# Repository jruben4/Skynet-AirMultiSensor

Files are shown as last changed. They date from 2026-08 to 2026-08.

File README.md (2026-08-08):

# Skynet-AirMultiSensor

| Front | Back |
|:---:|:---:|
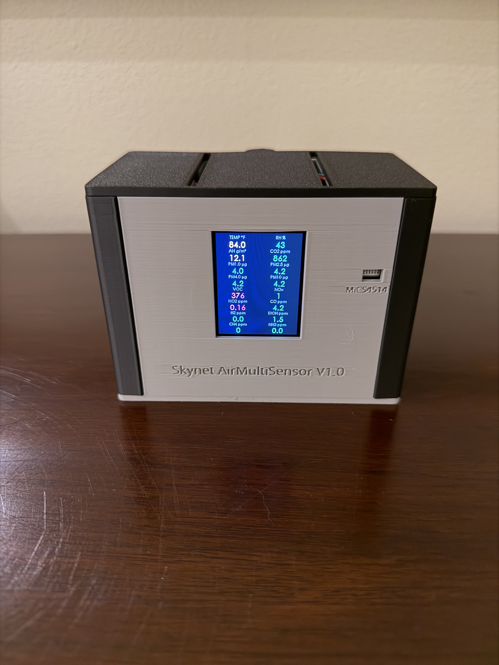
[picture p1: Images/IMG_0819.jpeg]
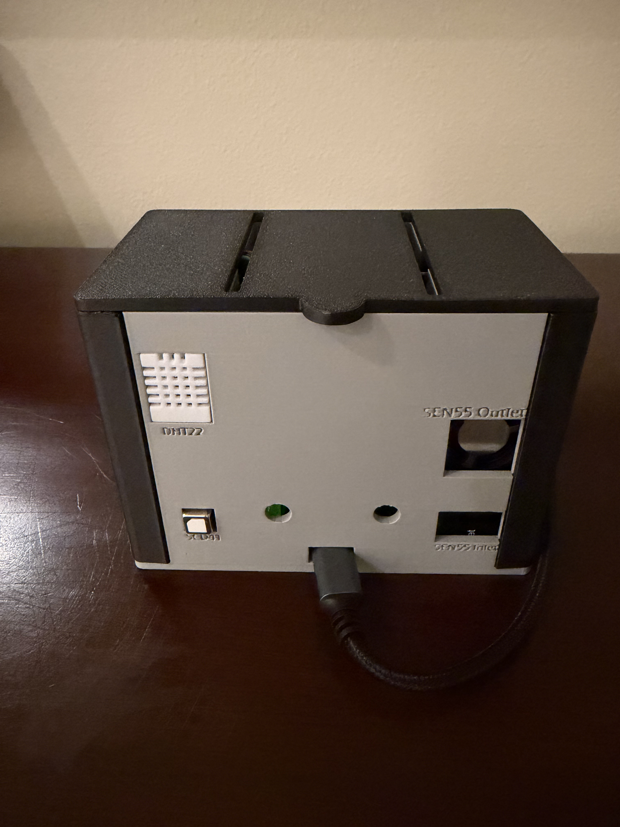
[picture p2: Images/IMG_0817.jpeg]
|  |  |

An ESPHome air-quality and climate monitor built on an ESP32, combining four top-of-class sensors: a DHT22 for temperature and humidity, a Sensirion SCD41 for true NDIR CO2, a Sensirion SEN55 for PM1.0/2.5/4.0/10 particulates plus VOC and NOx indices, and a MICS-4514 for nitrogen dioxide, carbon monoxide, hydrogen, ethanol, methane, and ammonia.  Extensive thermal considerations to provide as accurate sensor readings as possible, along with multiple calibration tools. Tight integration with Home Assistant, with sensors and calibration tools exposed via API. A 240×320 ST7789V color display shows the readings in one of three user-selectable modes, with every value color-coded green, amber, or red against configurable thresholds. Display mode, page rotation speed, sensor polling interval, temperature units, and backlight brightness are all adjustable  from Home Assistant. The device also is as an active Bluetooth proxy and BLE tracker.

---
## 📋 Table of Contents

- [Features](#features)
- [3D Model](#case-3d-model)
- [Hardware Bill of Materials (BOM) & Purchase Links](#-hardware-bill-of-materials-bom--purchase-links)
- [Saftey Notice](#safety-notice)
- [Wiring](#wiring)
- [Assembly](#assembly)
- [Software Installation](#softwarefirmeware-installation)
- [Home Assistant Integration](#home-assistant-integration)
- [Calibration](#calibrations)
- [References](#references)
 
 ---

## Features

- **High Accuracy Sensors** - Top-of-class specific sensor choices based on published accuracy data.  No more eCO2 or index gas levels.
- **16 live measurements** across temperature, humidity, CO2, particulates, VOC/NOx, and six trace gases
- **Three display modes**, switchable from Home Assistant:
  - **All 16** — dense single page, every value at once
  - **Rotating** — four pages of four values in large type, auto-advancing, with page indicator dots
  - **Highlight** — static page showing temperature, VOC, CO2, and PM2.5 only
- **Threshold color coding** — green below moderate, amber above moderate, red above high; thresholds drawn from EPA AQI breakpoints, WHO guidance, and OSHA/NIOSH exposure limits
- **Tight Integration with Home Assistant / ESPHome** — no reflashing needed to change display mode, rotation speed, sensor polling interval, °F/°C, or backlight brightness
- **Bluetooth proxy** — active proxy with 3 connections plus continuous BLE tracking, extending Home Assistant's Bluetooth range
- **Extensive Calibration Options** - For those who need even more accuracy! Temp, Humidity, CO2 calibrations
- **Gaussian Sensor Weighting** - provides a fused temperature and humidity readings based on the published performance of the different sensors.
- **Thermal Optimization** Thermal considerations and isolation were a big part of the case design, trying to prevent sensor/display related heating to effect sensor readings. Case designed to have the hot sensors far from the cooler sensors, and all sensors exposed to outside air instead of inside, and thermal insulation between center chamber and side chambers, and cooling chimneys on the top.

| Thermal Front | Thermal Back | 3D Print |
|:---:|:---:|:---:|
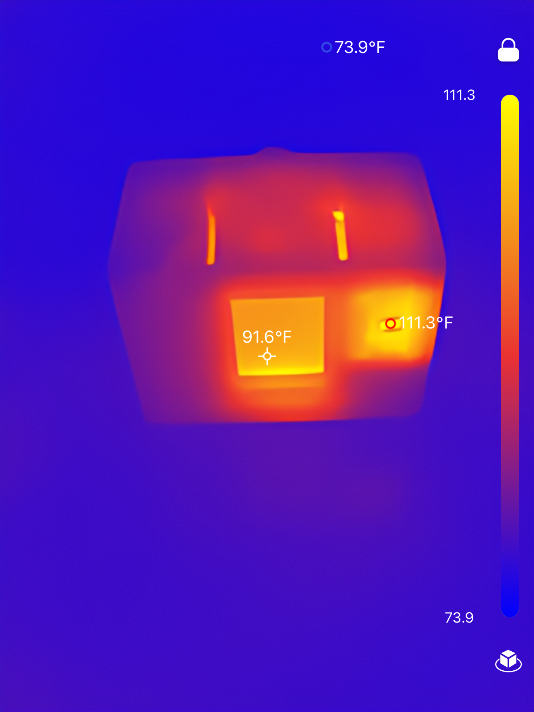
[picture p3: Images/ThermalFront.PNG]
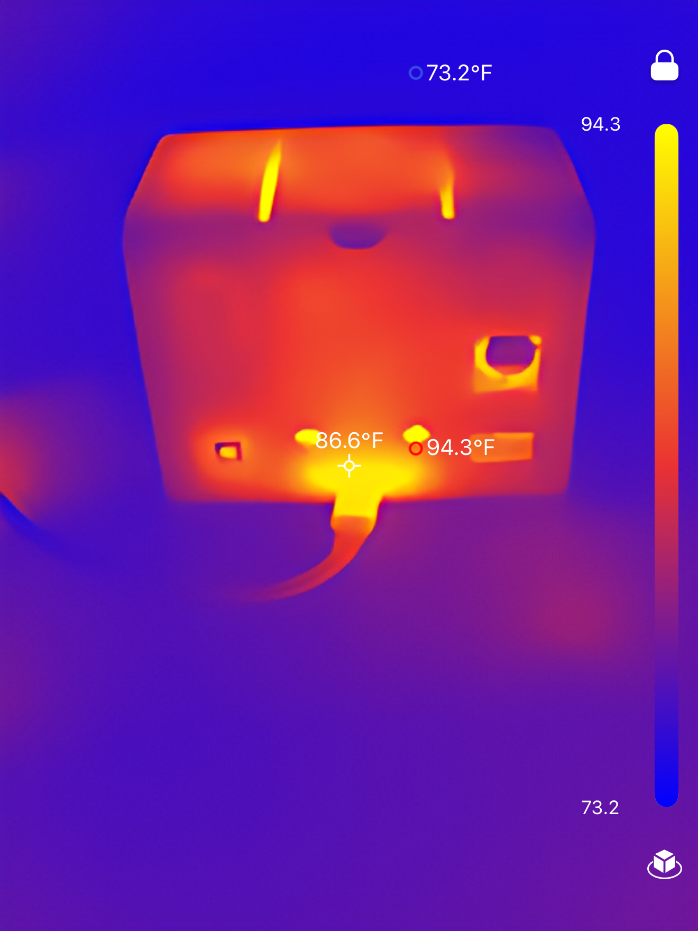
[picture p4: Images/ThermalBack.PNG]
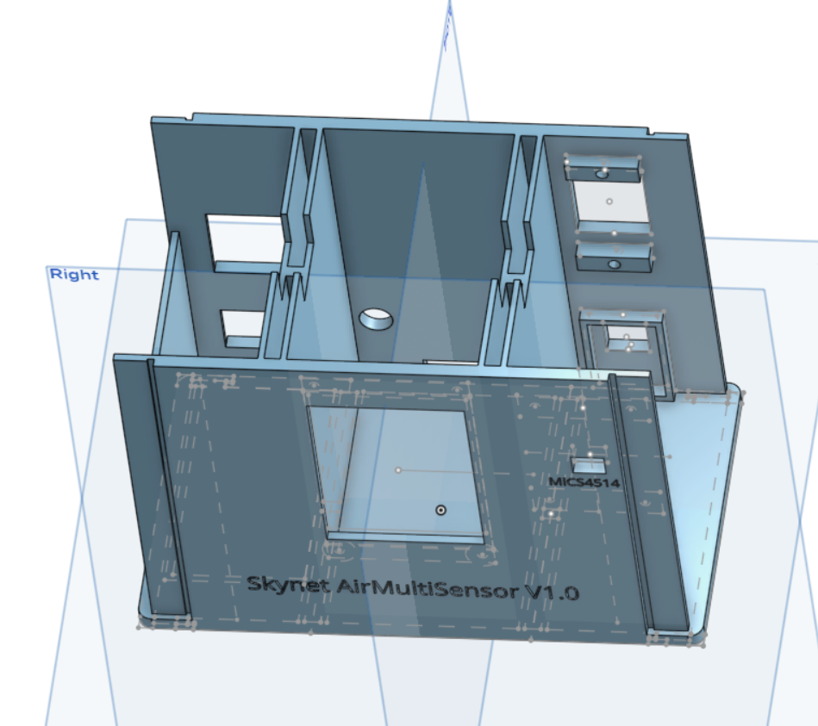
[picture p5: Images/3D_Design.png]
|  |  |  |

---

## Case 3D Model
All 3D printable files and print profiles for the enclosures are hosted on MakerWorld:

👉 [AirMultiSensor Case on MakerWorld](https://makerworld.com/en/models/3134930-skynet-air-multisensor)

---

## 🛒 Hardware Bill of Materials (BOM) & Purchase Links

| Component | Part | Interface | Link | Price $USD as of 8/26 |
|---|---|---|---|---|
| MCU | Freenove ESP32-WROOM (ESP32 rev3.1, 4MB flash, no PSRAM) | — | https://www.amazon.com/dp/B0C9THDPXP | 18.95 (for 2) |
| Temp / humidity | DHT22 (AM2302) | 1-Wire | https://www.amazon.com/dp/B0CPHQC9SF | 9.99 (for 3) |
| CO2 | Sensirion SCD41 | I²C bus A | https://www.amazon.com/dp/B0GWQMQVN8 | 19.99 |
| Particulate / VOC / NOx | Sensirion SEN55 | I²C bus B | https://www.seeedstudio.com/Grove-All-in-one-Environmental-Sensor-SEN55-p-5373.html | $59 | 
| Trace gases | MICS-4514 | I²C bus A | https://www.amazon.com/dp/B09G9PZ4XZ | 42.90 |
| Display | ST7789V 240×320 IPS, SPI | SPI (VSPI) | https://www.amazon.com/dp/B082GFTZQD | 17.27 |
| Grove breakout cable (optional) | — | — | https://www.amazon.com/dp/B074MDM36N | 9.99 (for 5) |
| M3x4 and M2x4 screws | - | - | - |
| USB-C power cable | - | - | - |

---

## Safety notice

**This is not a safety device.** The MICS-4514 is an uncalibrated metal-oxide sensor whose readings drift substantially with temperature and humidity; its ppm figures are useful as relative trends, not absolute concentrations. Do not rely on the carbon monoxide reading for life safety — use a certified CO alarm. The same applies to the methane channel and gas leak detection.

This project was made partially with assistance using Claude. 3D models were designed manually using OnShape.

---

## Wiring

You will be making two different I2C buses.  The SCD41 and 4515 chips are on one, and the SEN55 is by itself on the other.

There should be cables that came with the SCD41 grove chip, as well as the SEN55 Gravity sensor.  Below are the colors that I had:

Grove cable (for the Sen55) - white = SDA, Yellow = SCL, Red = 5V, Black = Ground

Gravity cable (for the SCD41) - green = SDA, Blue = SCL, Red = 3.3V, Black = Ground

1. Bus 1: Splice together and I2C "bus" for the SCD41 and Gravity 4515 chips (connect power, ground, SDA, SCL of the two sensors, and also connect them to jumpers that end in breadboard connectors to plug into the ESP32 pins).  SCL for this bus goes to RX (GPIO17), and SDA - GPIO26
2. Bus 2: Make a second I2C "bus" for the gravity SEN55 sensor - Can use the Gravity cable that comes with the chip and cut off the non-gravity side and splice onto breadboard connectors, or purchase the premade cable (link above). SCL for this bus goes to GPIO22, SDA - GPIO21
3. Power Bus#1 goes to 3.3V pin, Bus#2 goes to 5V, both buses ground goes to ground.

4. Make sure to solder the pins to the SCD41 board to the backside (opposite the sensor)
5. DHT22: 3.3V, GND, signal to GPIO25

6. Display hookup (these are the colors of the cable that came with my display, YMMV):
DC - blue - GPIO4
CS - yellow - GPIO5
RST - brown - GPIO27
CLK - orange - GPIO18
DIN (MOSI) - green - GPIO23
VCC - purple - 3.3V
GND - white - GND
BL - grey - GPIO32

## Assembly

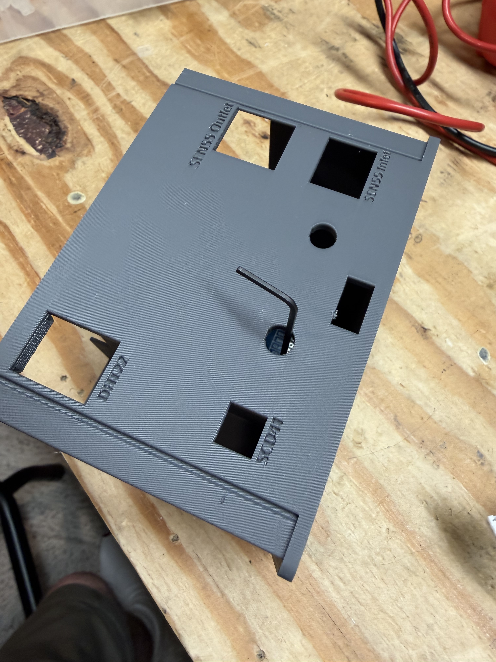
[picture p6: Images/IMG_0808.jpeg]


1. Attach Display with M2x4 screws.  Plug goes on top.  Use a allen wrench key through the back holes to get the bottom two screws in.
2. Place SCD41, secure with two-sided tape on the front-facing side below the sensor box.
3. Attach DHT22 above it (with jumpers attached already) with M3x4 screws
4. Attach MICS with M2x4 screws
5. Slide the ESP32 in the center section, under the display, usb facing the hole and pins pointing up
6. Attach USB-C power cable into ESP32 through back hole.
7. Make sure the sensor cables that travel from the center section to the left/righ sections are sitting in the channel gaps in the separating walls before you put the lid on to prevent them being pinched.

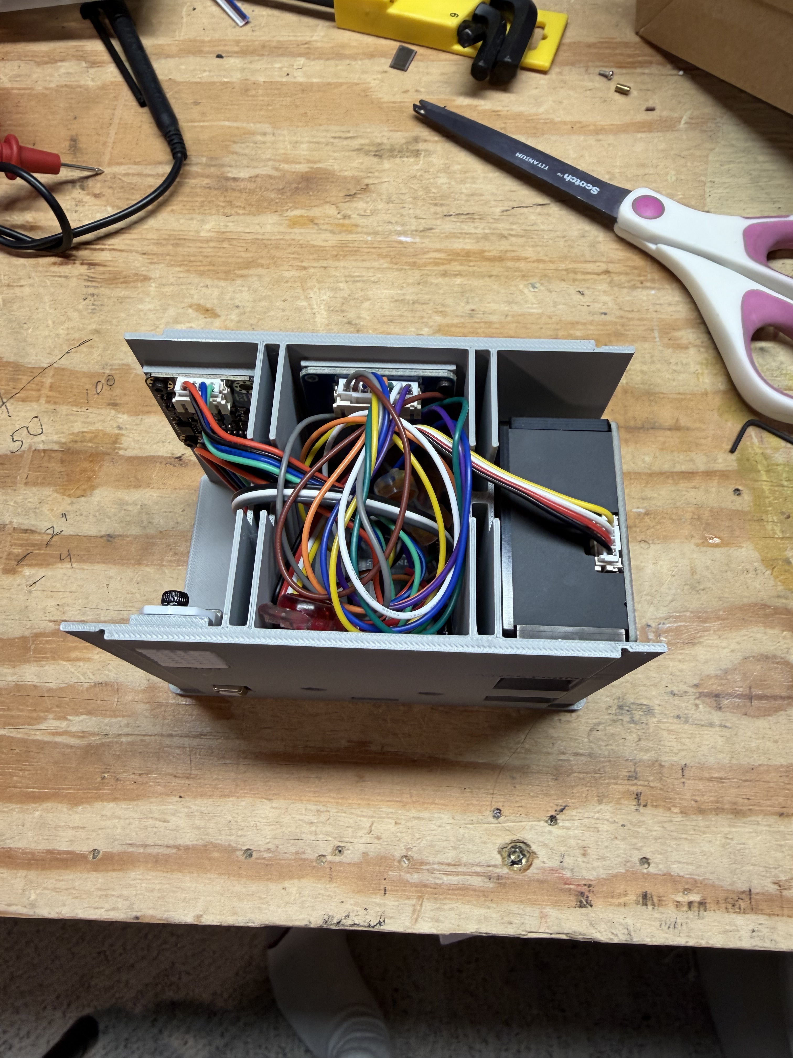
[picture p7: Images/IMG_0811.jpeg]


## Software/Firmeware Installation

1. This assumes you're already running [ESPHome](https://esphome.io/) (2026.7.3 or later — the config uses `mipi_spi`).
2. Copy the contents of skynet-multisensor.yaml from this repo into an empty new device in ESPhome.
2. Add `wifi_ssid` and `wifi_password` to your `secrets.yaml` or add them to this yaml (instead of !secret wifi_ssid and !secret wifi_password)
3. Replace the AP password (!secret master_skynet_multisensor__ap_password), API encryption key (!secret master_skynet_multisensor__encryption_key), OTA password (!secret master_skynet_multisensor__ota_password), and uncomment and modify `use_address` with your own (optional).
4. Flash over USB the first time. **USB flashing is required at least once** — `sram1_as_iram: true` needs a bootloader from ESP-IDF 5.1 or later, and bootloaders do not update over OTA.  https://web.esphome.io/ works well.
5. Add the new device to home assistant / ESPHome integration.  You'll need the encryption key you made in step 3.

### Notes on first boot

- The MICS-4514 needs several minutes of heater warm-up before it reports; expect `--` on those values initially.
- The SEN55 VOC and NOx algorithms need hours to establish a baseline. Early index values are not meaningful.
- If the display renders as a photo negative, flip `invert_colors` in the display block. Roughly half of ST7789V panels want it one way, half the other.

---

## Home Assistant Integration

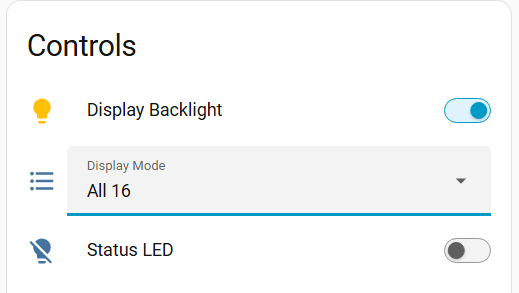
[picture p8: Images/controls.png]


1) Diplay backlight - turning this off will blank display
2) Display mode:
    - All 16 - all 16 sensors on a single screen, but small
    - Rotating - 4 sensors on each screen (bigger), rotating through 4 pages (speed adjustable)
    - Highlights - 4 sensors on single screen (bigger) - temp, VOC, PM2.5, and CO2.

<p align="left">

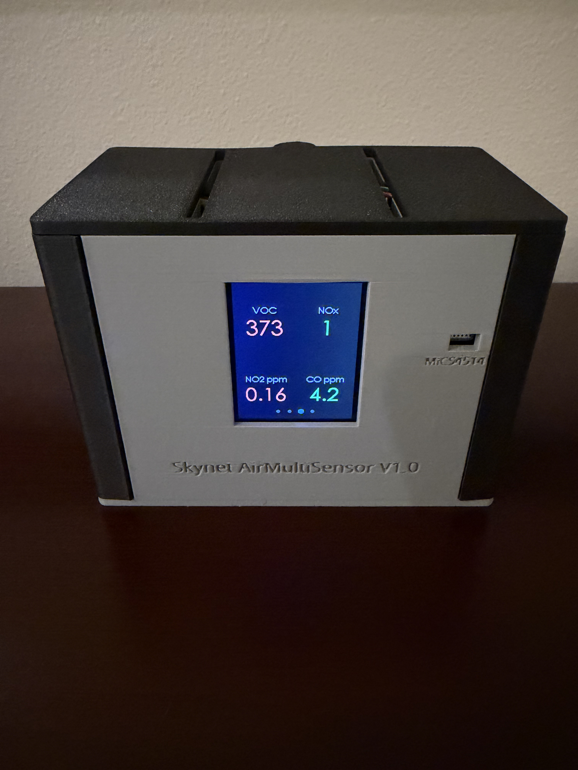
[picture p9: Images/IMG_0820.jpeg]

</p>

3) Status LED - there is an on-chip light that is controlable, but probably not visable from outside the case.

---

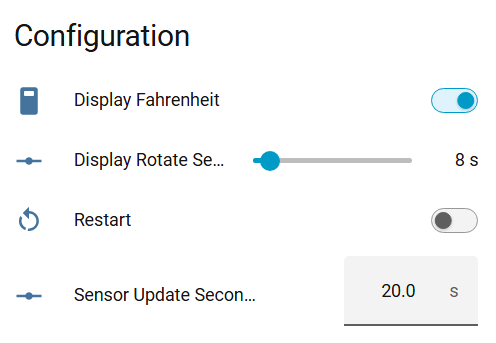
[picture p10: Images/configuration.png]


1) Display Fahrenheit - If on, the display will show temp in F.  If not, C.  (both are transmitted to home assistant)
2) Display Rotation Speed - if on "rotating" diplay mode, this will adjust how fast the pages will cycle
3) Restart - will reboot ESP
4) Sensor update - adjust the update speed of all the sensors.  10s is the minimum.

---

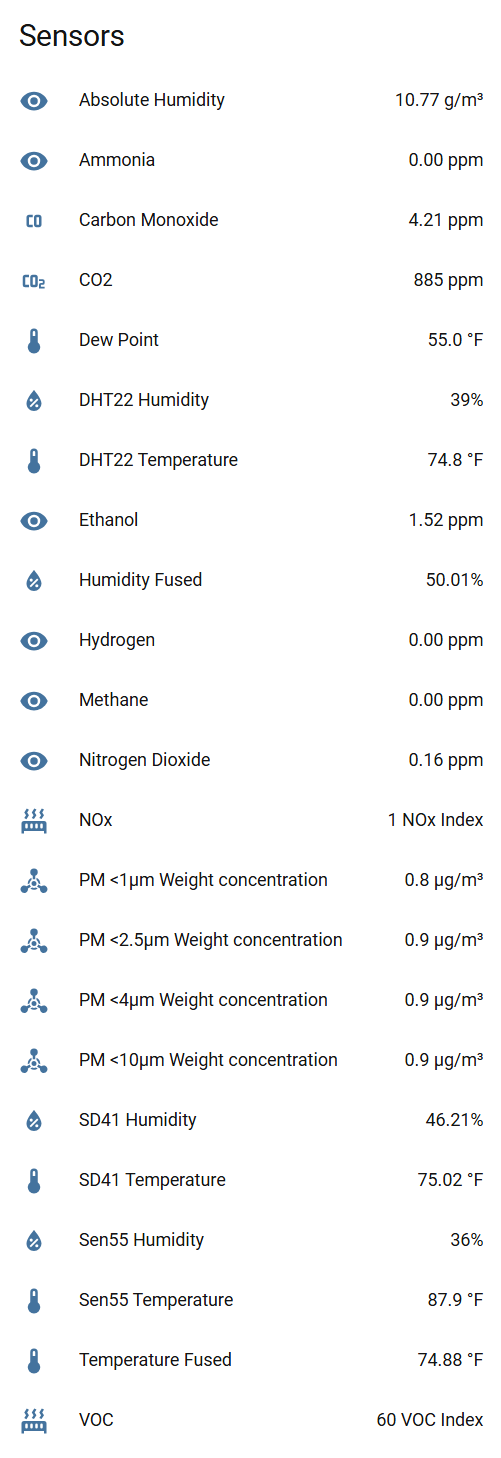
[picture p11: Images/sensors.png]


1) Sensor data exposed to home assistant shown above.  Note "Temperature Fused" and "Humidity Fused" are caculated from all 3 sensors and adjusted by known sensor accuracy.  Absolute Humidity and Dew Point are also calculated from the fused data.
2) Wifi data also available "Diagnostic" panel - not pictured.

---

## Calibrations

1) Set Ambient Pressure: The SCD41 relies on accurate atmospheric pressures to report CO2 - not setting this can cause variations up to 20%.  Use a home assistant automation to pull current atmospheric pressure from some other sensor (or web API) in mbar and push it to the sensor.  Set an automation with a time trigger ~ 1 hr with the action:

```yaml
action: esphome.skynet_multisensor_set_ambient_pressure
data:
  pressure_mbar: "{{ states('sensor.air_pressure') | int(0) }}"
```
You can see the last "sent" pressure and how long ago it was updated to make sure your automation is feeding ESPHome correctly.




2) Temperature bias - there are three sensors that report temps (DHT22, SCD41, SEN55).  Care was taken to try to thermally isolate, but they still  experience local heating as the whole sensor package warms up over time.  Let the device become cold/room temperature (off for at least an hour) and then start it up.  Under the Diagnostic window in home assistant you'll find Boot temps and Warm temps (after 30 min) from the sensors, and a Bias estimate which is how much the temp rose (assuming the room stayed the same over those 30 minutes). Of note, these cold/warm values will only populate after a power-on from off (not just reset) to prevent you losing the values on simple reset (the point is to get these cold numbers after being powered off for a while). These value can be adjusted in the home assistant card.  You'll see they are unit-less degrees - they will represent F or C depending on how the "Display Fahrenheit" toggle is set.  A larger bias value will bring down the displayed temp from that sensor.  I have the offsets I measured on mine as the defaults.

<p align="left">
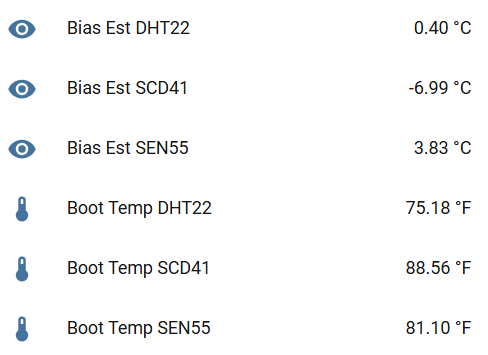
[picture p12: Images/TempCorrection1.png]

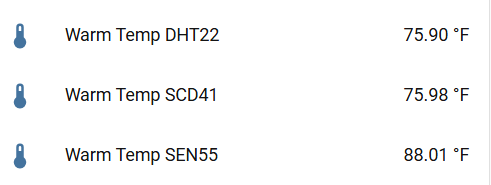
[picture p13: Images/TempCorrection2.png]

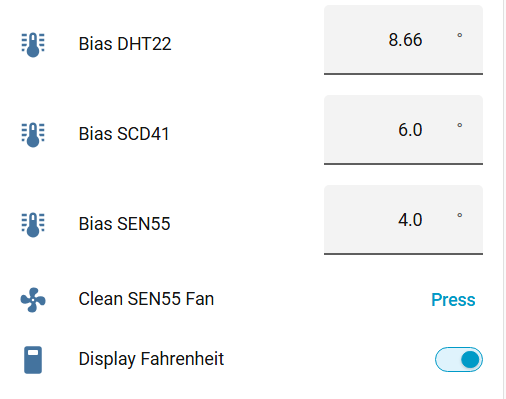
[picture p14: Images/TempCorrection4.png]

</p>

3) If you REALLY want you can calibrate the relative humidity with a salt calibration, these values are also in the YAML "rhbias_dht", etc.

4) SCD41 CO2 Automatic self-calibration assumes the sensor sees ~400 ppm background weekly. If this lives in a room that never fully vents, ASC will drag your baseline wrong and you won't know. There is a forced-calibration button (target 420 ppm, after 3+ min outdoors) so you can correct it without reflashing.  You will need to set "scd_asc" to false in the yaml if you plan on occasional manual outdoor calibrations, otherwise it will auto-calibrate back to the room CO2 in a week.  There is an ARM CO2 Calibration button that needs to be on first, to prevent accidental calibration runs.  Let it power on outside for 5 minutes to let the readings settle before running calibration.  If your outdoor CO2 isn't around 420, this can be adjusted in the YAML as well to calibrate it to the current outdoor CO2.

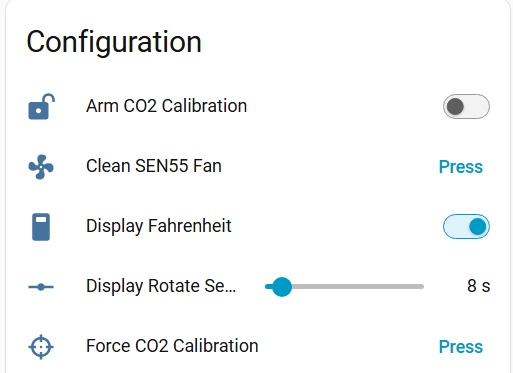
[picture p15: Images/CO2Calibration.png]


5) The Sen55 will autoclean weekly.  There is a button exposed to home assistant - "Clean SEN55 Fan" - if you would like to manually trigger a clean (the fan spins up to ~10s at full speed to blow it clear.)

---

## References

### I²C — two buses

Two separate buses are used because the SEN55 and SCD41 both benefit from short, clean runs, and splitting them keeps each bus lightly loaded.

| Bus | Signal | GPIO | Devices |
|---|---|---|---|
| **Bus A** | SDA | `GPIO26` | SCD41, MICS-4514 |
| **Bus A** | SCL | `GPIO17` | |
| **Bus B** | SDA | `GPIO21` | SEN55 |
| **Bus B** | SCL | `GPIO22` | |

Both buses run at 50 kHz. 

### DHT22

| Signal | GPIO |
|---|---|
| Data | `GPIO25` |

Internal pull-up is enabled in firmware.

### Display — ST7789V over SPI

The ST7789V is write-only, so there is no MISO connection.

| Display pin | GPIO | Notes |
|---|---|---|
| GND | GND | |
| VCC | 3.3 V | **not 5 V** — bare breakouts have no regulator |
| SCL / CLK / SCK | `GPIO18` | SPI clock |
| SDA / DIN / MOSI | `GPIO23` | SPI data — this is MOSI, *not* I²C |
| RES | `GPIO27` | Reset |
| DC | `GPIO4` | Data/command |
| CS | `GPIO5` | Chip select |
| BLK | `GPIO32` | Backlight, LEDC PWM, dimmable |

### Full GPIO map

| GPIO | Function |
|---|---|
| 4 | Display DC |
| 5 | Display CS |
| 16 | WS2812 status LED |
| 17 | I²C bus A — SCL |
| 18 | SPI CLK |
| 21 | I²C bus B — SDA |
| 22 | I²C bus B — SCL |
| 23 | SPI MOSI |
| 25 | DHT22 data |
| 26 | I²C bus A — SDA |
| 27 | Display RESET |
| 32 | Display backlight (PWM) |

GPIO5 is technically a strapping pin, but it's the ESP32's default VSPI CS and idles high, so it's safe here. ESPHome will warn about it regardless.

---

## Home Assistant entities

### Sensors

| Entity | Unit |
|---|---|
| DHT22 Temperature | °C |
| DHT22 Temperature F | °F |
| DHT22 Humidity | % |
| DHT22 Absolute Humidity | g/m³ |
| CO2 | ppm |
| SD41 Temperature / Humidity | °C / % |
| PM <1µm, <2.5µm, <4µm, <10µm | µg/m³ |
| Sen55 Temperature / Humidity | °C / % |
| VOC / NOx | index |
| Nitrogen Dioxide, Carbon Monoxide, Hydrogen, Ethanol, Methane, Ammonia | ppm |
| WiFi Signal dB / Percent | dBm / % |

### Controls

| Entity | Type | Range / options |
|---|---|---|
| Display Mode | select | All 16 · Rotating · Highlight |
| Display Rotate Seconds | number | 2–60 s |
| Sensor Update Seconds | number | 10–600 s |
| Display Fahrenheit | switch | on / off |
| Display Backlight | light | dimmable |
| Status LED | light | RGB |
| Restart | switch | — |

---

## Thresholds

Set in `substitutions:` at the top of the YAML. Each value has a *moderate* and *high* cutoff.

| Measurement | Moderate | High | Basis |
|---|---|---|---|
| Temperature | 80 °F / 26 °C | 90 °F / 32 °C | comfort |
| Humidity | 60 % | 70 % | comfort / mould risk |
| Absolute humidity | 12 g/m³ | 17 g/m³ | comfort |
| CO2 | 1000 ppm | 1500 ppm | common IAQ guidance |
| PM1.0 / PM2.5 | 12 µg/m³ | 35 µg/m³ | EPA AQI breakpoints |
| PM4.0 | 25 µg/m³ | 50 µg/m³ | interpolated |
| PM10 | 54 µg/m³ | 154 µg/m³ | EPA AQI breakpoints |
| VOC index | 150 | 250 | Sensirion (100 = baseline) |
| NOx index | 20 | 150 | Sensirion (1 = clean) |
| NO2 | 0.05 ppm | 0.10 ppm | WHO |
| CO | 9 ppm | 35 ppm | EPA 8 h / 1 h standards |
| H2 | 50 ppm | 100 ppm | relative |
| Ethanol | 50 ppm | 100 ppm | relative |
| Methane | 1000 ppm | 5000 ppm | ~2 % / ~10 % of LEL |
| Ammonia | 25 ppm | 50 ppm | NIOSH REL / OSHA PEL |

Thresholds are one-sided — they only flag values that are too *high*. A cold room shows green.

## License

[PolyForm Noncommercial License 1.0.0](LICENSE) — free for personal, hobby, educational, research, and nonprofit use. Commercial use is not permitted.

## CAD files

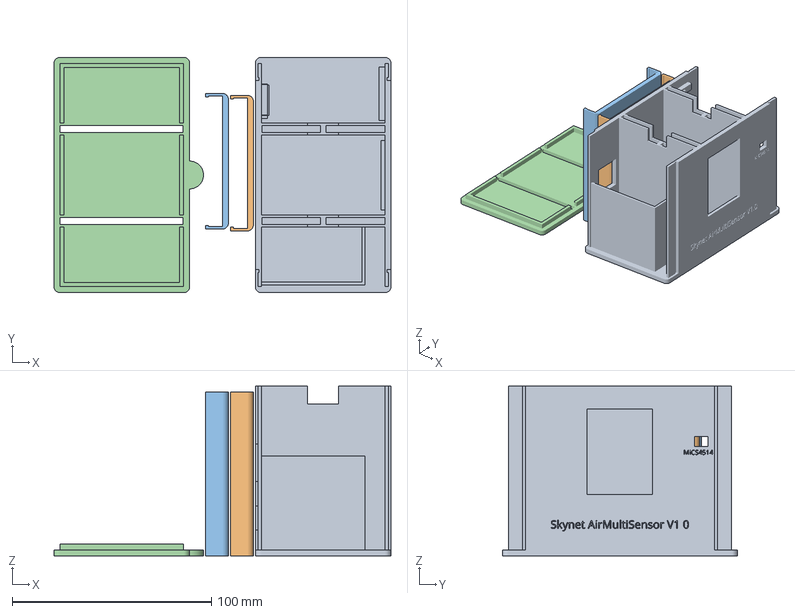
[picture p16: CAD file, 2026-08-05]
SkynetAirMultisensor.3mf
169.0 x 118.0 x 85.0 mm
Main Case (3).stl
Sides (2).stl x 2
Top.stl

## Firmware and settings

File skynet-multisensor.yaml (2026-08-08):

substitutions:
  devicename: skynet-multisensor
  upper_devicename: SkynetMultiSensor

  # ---- thresholds: moderate / high ----
  temp_mod_f:   "80"    # °F
  temp_high_f:  "90"
  temp_mod_c:   "26"    # °C
  temp_high_c:  "32"
  rh_mod:     "60"      # %
  rh_high:    "70"
  ah_mod:     "12"      # g/m³
  ah_high:    "17"
  co2_mod:    "1000"    # ppm
  co2_high:   "1500"

  pm1_mod:    "12"      # µg/m³
  pm1_high:   "35"
  pm25_mod:   "12"      # EPA AQI good/moderate boundary
  pm25_high:  "35"      # unhealthy for sensitive groups
  pm4_mod:    "25"
  pm4_high:   "50"
  pm10_mod:   "54"      # EPA AQI breakpoints
  pm10_high:  "154"

  voc_mod:    "150"     # Sensirion index, 100 = baseline
  voc_high:   "250"
  nox_mod:    "20"      # index, 1 = clean
  nox_high:   "150"

  no2_mod:    "0.05"    # ppm
  no2_high:   "0.10"
  co_mod:     "9"       # ppm, EPA 8h standard
  co_high:    "35"      # EPA 1h standard
  h2_mod:     "50"
  h2_high:    "100"
  etoh_mod:   "50"
  etoh_high:  "100"
  ch4_mod:    "1000"    # ppm, ~2% of LEL
  ch4_high:   "5000"    # ~10% of LEL
  nh3_mod:    "25"      # NIOSH REL
  nh3_high:   "50"      # OSHA PEL

  # ---- self-heating corrections ----
  #  Defaults, in DEGREES CELSIUS, for the three "Bias ..." number entities.
  #  After the first flash the live values come from Home Assistant and are
  #  restored across reboots, so editing these has no effect on a running
  #  device unless you also change the number in HA.
  #
  #  The numbers are expressed in whatever unit the Display Fahrenheit
  #  switch selects. Because a bias is a temperature DIFFERENCE, the
  #  conversion is x1.8 only - there is no +32 term. Flipping the switch
  #  rescales the stored values so the physical correction is unchanged.
  #
  #  All three are applied as ESPHome filters (x - bias) rather than in the
  #  sensors' own offset registers, because those registers are written once
  #  at setup() and cannot be changed at runtime.
  bias_dht:  "4.81"
  bias_scd:  "3.39"
  bias_sen:  "5"
  # Range must cover both units: +-20 C is about +-36 F.
  bias_min:  "-20"
  bias_max:  "40"
  # ---- 1-sigma (°C). Datasheet "typ. accuracy" treated as 2-sigma. ----
  sigma_dht: "0.25"
  sigma_scd: "0.40"
  sigma_sen: "0.225"
  outlier_k: "3.0"     # residual gate, in sigmas

  # ---- residual RH bias (%RH), from salt calibration. Usually 0. ----
  rhbias_dht: "0.0"
  rhbias_scd: "0.0"
  rhbias_sen: "0.0"
  # ---- 1-sigma (%RH) ----
  sigma_dht_rh: "1.75"   # spec ±2 inflated to ±3.5; use 1.0 if verified
  sigma_scd_rh: "3.00"
  sigma_sen_rh: "2.25"
  rh_outlier_k: "3.0"

  # ---- SCD41 CO2 calibration ----
  #  ASC assumes the sensor sees a ~400 ppm background at least weekly.
  #  In a room that never fully vents that assumption fails silently and
  #  drags the baseline. Set scd_asc to "false" if this unit lives in
  #  such a room, and use the forced-calibration button instead.
  scd_asc:   "true"
  fcal_ppm:  "420"       # outdoor reference for forced recalibration
  cal_arm_timeout: "5min"   # arm switch auto-disarms after this

  # ---- cold-start capture ----
  boot_poll_ms:    "10000"    # fast poll rate until boot temps latch
  boot_timeout_tk: "150"      # give up after N x 2s ticks (150 = 5 min)
  warm_delay_ms:   "1800000"  # steady-state sample at 30 min uptime
  scd_min_ms:      "10000"    # never poll the SCD41 faster than this
  # Stale-data guard. Must exceed the largest Sensor Update Seconds (600s),
  # or sensors would go NaN between normal updates.
  stale_timeout:   "15min"

esphome:
  name: $devicename
  friendly_name: $upper_devicename

esp32:
  board: nodemcu-32s
  framework:
    type: esp-idf
    advanced:
      minimum_chip_revision: "3.1"
      sram1_as_iram: true

wifi:
  ssid: !secret wifi_ssid
  password: !secret wifi_password
  #use_address: 192.168.5.51
  min_auth_mode: WPA2
  # Enable fallback hotspot (captive portal) in case wifi connection fails
  ap:
    ssid: ${upper_devicename} Hotspot
    password: !secret master_skynet_multisensor__ap_password

captive_portal:

ota:
  - platform: esphome
    password: !secret master_skynet_multisensor__ota_password

# Enable logging
logger:

# Enable debug
debug:
  update_interval: 60s

# Enable Home Assistant API
api:
  encryption:
    key: !secret master_skynet_multisensor__encryption_key
  actions:
    - action: set_ambient_pressure
      variables:
        pressure_mbar: int
      then:
        - lambda: |-
            id(my_scd41)->set_ambient_pressure_compensation(pressure_mbar);
            id(last_pressure) = (float) pressure_mbar;
            id(last_pressure_ms) = millis();
            ESP_LOGI("pressure", "Ambient pressure set to %d mbar", (int) pressure_mbar);

  reboot_timeout: 0s
esp32_ble_tracker:
  scan_parameters:
    interval: 320ms
    window: 100ms     # ~31% duty
    active: false

bluetooth_proxy:
  active: true
  connection_slots: 1
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

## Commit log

2026-08-05 Add 3D print
2026-08-08 Move temp correction to home assistant card.
    [skynet-multisensor.yaml]
